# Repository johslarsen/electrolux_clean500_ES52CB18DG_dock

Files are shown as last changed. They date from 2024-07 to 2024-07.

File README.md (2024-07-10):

# Dock for 18V Electrolux Clean 500 (ES52CB18DG)

This stripped down version of a vacuum did not come with charging dock. Instead
it comes with a plain barrel jack DC power supply. Here is a wall attachment
for the barrel jack, which snugly fits the vacuum unit and guides the plug into
the charge port:

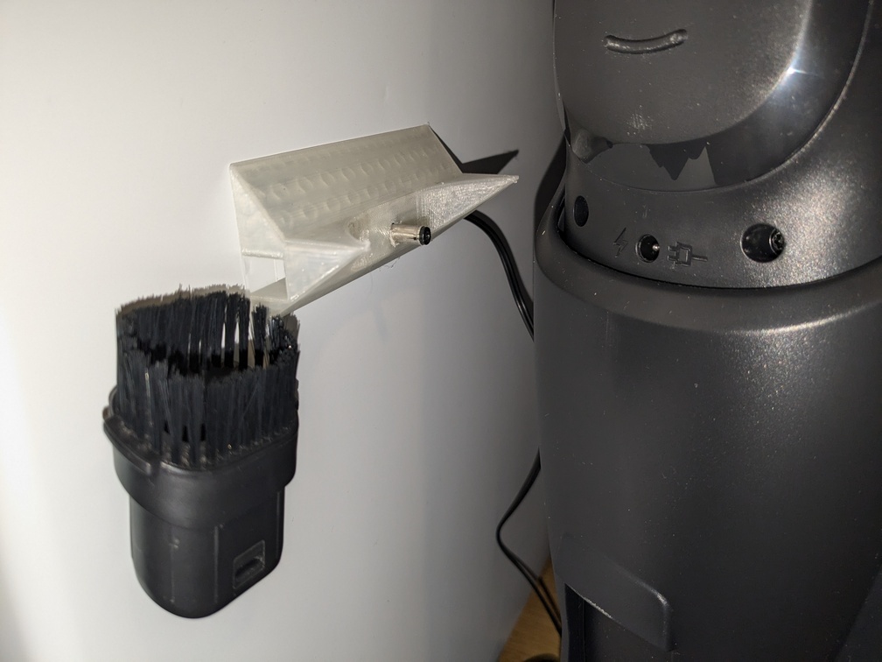
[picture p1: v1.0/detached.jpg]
dock and vacuum detached

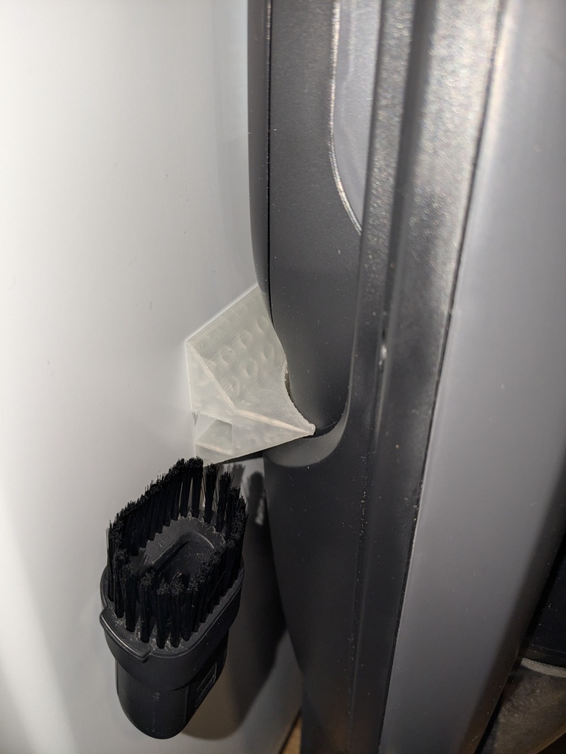
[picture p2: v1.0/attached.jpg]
dock and vacuum attached


## Bonus features

The extra short nozzle (as shown on the left side of the pictures above) can be
attached to magnetic surfaces by gluing some small magnets to it.

This vacuum also lacked LED lights on the front of the floor brush, which are
common nowadays (e.g. the predecessor to this vacuum!). Luckily the floor brush
is motorized, and soldering some 24V LED-strips in parallel with that motor
works nicely:

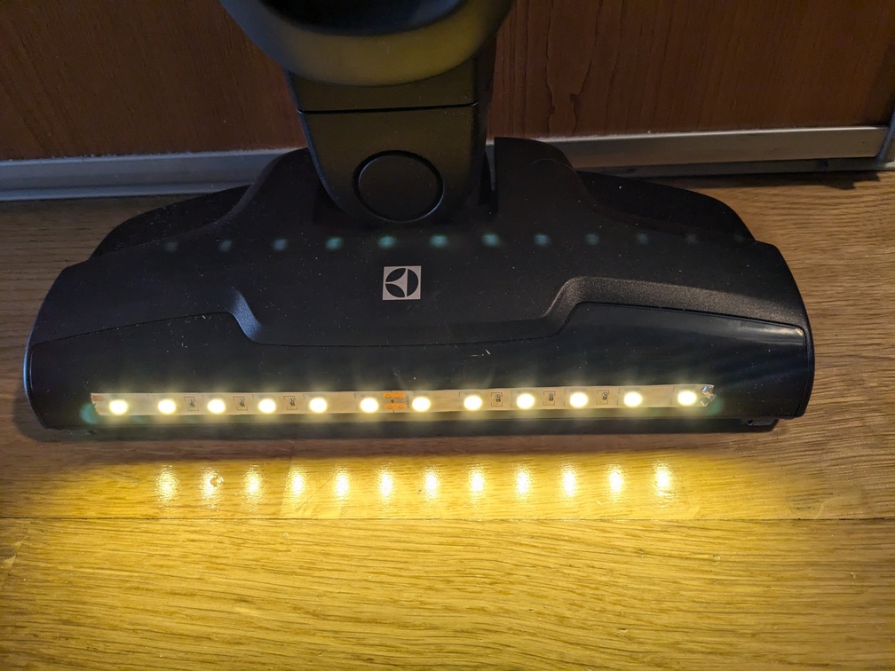
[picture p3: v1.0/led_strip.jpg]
vacuum brush with LED-strips


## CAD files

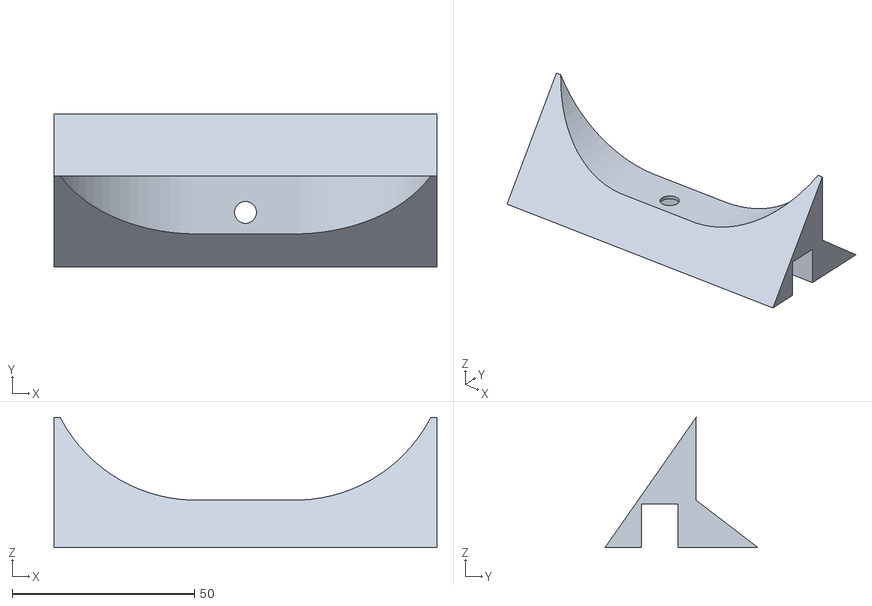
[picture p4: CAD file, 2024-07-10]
v1.0/dock.stl
105.0 x 42.0 x 35.7

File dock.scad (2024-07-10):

plugD = 6;
plugW = 10;
plugH = 12;

l = 105;
h = 30 + plugH;

w1 = 20;
w2 = 42;

y = 15;
bottomAngle = 55;

t = 1.0;

difference()
{
    translate([ -l / 2, -y, -plugH ]) cube([ l, w2, h ]);

    translate([ 0, 0, -plugH - .01 ]) cylinder(d = plugD, h = h + .02);
    translate([ -l / 2 - .01, -plugW / 2, -plugH - .01 ]) cube([ l + .02, plugW, plugH ]);

    r = h;
    hull()
    {
        translate([ plugH / 4 + l / 2 - r, .01 + w2 - y, r + t ]) rotate([ 90, 0, 0 ]) cylinder(r = r, h = w2 + .02);
        translate([ -l / 2 + r - plugH / 4, .01 + w2 - y, r + t ]) rotate([ 90, 0, 0 ]) cylinder(r = r, h = w2 + .02);
    }
    hull()
    {
        translate([ -l / 2 - .01, w1 / 2, t ]) cube([ l + .02, 0.1, h ]);
        translate([ -l / 2 - .01, w2 - y, -plugH ]) cube([ l + .02, 0.1, h ]);
    }
    translate([ -l / 2 - .01, -y, -plugH ]) rotate([ bottomAngle, 0, 0 ]) cube(l + .02);
}

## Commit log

2024-07-08 First attempt
    Does not fit. Lower angle needs to be closer to plug, and there is no
    grip in the body radius
    [dock.scad]
2024-07-09 2nd attempt
    Fits, but radius is still too small to cling it properly. There is also
    a lot of room for extra height, although extra angled top bottom plane
    would eat it up pretty soon.
    [dock.scad]
2024-07-10 3rd attempt. fits snugly
    [dock.scad]
2024-07-10 Release this into public domain, and render a v1.0 with descriptions and images
    [dock.stl]
